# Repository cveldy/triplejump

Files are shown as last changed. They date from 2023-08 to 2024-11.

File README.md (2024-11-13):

# triplejump

Leverless (Hitbox-style) fighting game controller with ~~three~~ two jump options.

`TODO: One or more images`

## About

This controller is distinguished by its split-hand configuration and angled keyclusters, mitigating the RSI-potential of the standard "hands-together-but-parallel" layout popularized by the Hitbox. The goal is to keep the entire device relatively small while still providing a meaningful ergonomic benefit.

Another notable aspect of the layout is the 10 button right hand cluster. The closeness of the keys in this keyboard-like format makes multi-key inputs (e.g., `LP+LK`) harder than usual to press. Promoting `R3` and `L3` into "first class" buttons mitigates this drawback by providing more locations for macros (the legal kind you can map in-game).

Lastly are the titular ~~three~~ two up buttons. This allows the same handed-preference for jumping (and ability to double-tap using both thumbs) from the normal layout.

Powering this device is OpenStick's excellent [GP2040-CE](https://github.com/OpenStickCommunity/GP2040-CE) gamepad firmware. Please see that repository for information about configuration, console compatibility, and all the rest.

## Creation

If you want to produce one, you will need some parts.

### PCB

- 1x triplejump PCB, created using the [gerbers.zip](./prod/gerbers.zip) files with an online PCB prototyping service. (e.g., [JLCPCB](https://jlcpcb.com/).)
- 1x [RP2040-Zero](https://www.waveshare.com/rp2040-zero.htm).
- 5x 6x6mm Panel PCB Momentary Tactile Mini Push Button Switch DIP 4pin.
- 15x Kailh Choc v1 Hotswap Sockets (PG1350).

### Keys

- 15x Kailh Choc v1 Switches (recommended: linear switches with low actuation force).
- 13x Kailh Choc-compatible 1u Keycaps.
- 2x Kailh Choc-compatible 1.5u Keycaps.

### Case

This case was designed with MBK profile Choc keycaps in mind and may or may not be compatible with other keycaps.

- Laser Cut Acrylic Layers: [Bottom](<./prod/case_layer0_1.5mm.dxf>), [Lower-Middle](<./prod/case_layer1_3mm.dxf>), [Upper-Middle](<./prod/case_layer2_4.5mm.dxf), [Top](<./prod/case_layer3_1.5mm.dxf>)
  - The filenames include how thick each layer should be.
  - The PCB goes between the two middle layers.
- 6x M3 x 12mm Bolts.
- 6x M3 x 6mm Barrel Nuts.
- OPTIONAL: Non-slip Feet or Pads.

### Assembly

- Soldering Equipment.
- Screwdriver.

### Firmware

- The [Latest GP2040-CE Release](https://github.com/OpenStickCommunity/GP2040-CE/releases), flashed accoridng to the documentation.
- Pin (Button) Mapping using GP2040-CE's [Web Configurator](https://gp2040-ce.info/#/web-configurator)
  - There is a catch: the firmware assumes a default pin mapping that the triplejump does not use. Until you've remapped the pins, you must hold down L1 instead of S2 (Start) when plugging in the controller to enter the configurator.
  - You could also short pin 1 to ground manually if you haven't installed the switches yet when setting up the firmware.
  - The correct mapping for the triplejump is shown below.

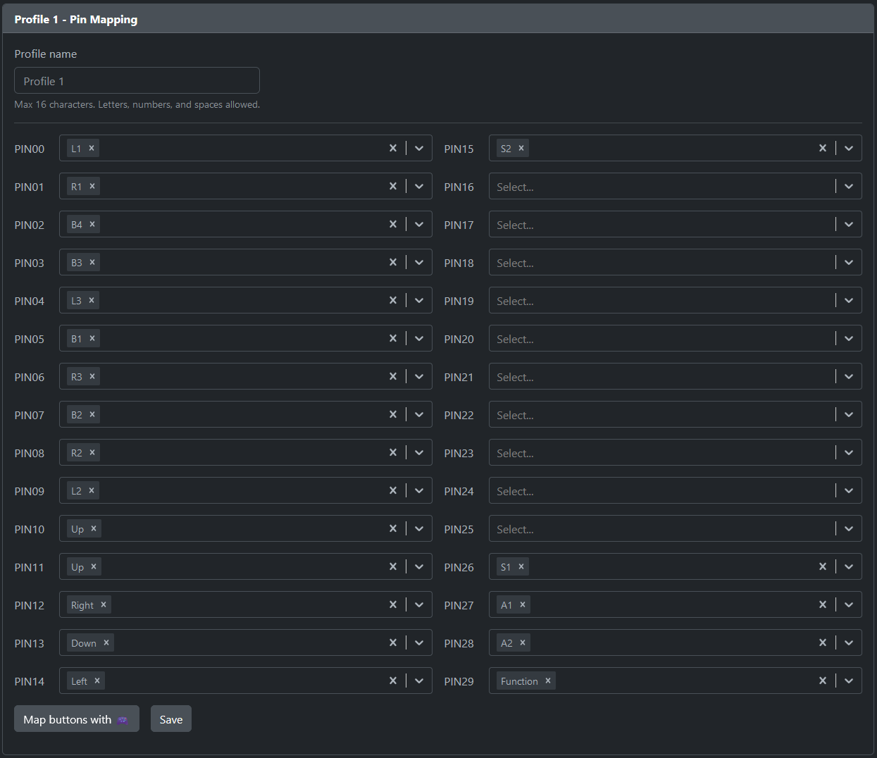
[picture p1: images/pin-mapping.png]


### Art

Optionally, you could print some art and put it between the top two acrylic layers. An [Art Template](<./prod/triplejump_art_template.psd>) is provided, though I haven't tested it personally.

## Acknowledgments

- [GrooveBob](https://github.com/GroooveBob)'s [Stress](https://github.com/GroooveBob/Stress), which helped inspire this design.
- [jfedor2](https://github.com/jfedor2)'s [Flatbox](https://github.com/jfedor2/flatbox), which helped inspire this design.
- [Afternoon Labs](https://github.com/afternoonlabs)' [Breeze](https://github.com/afternoonlabs/BreezeKeyboard), which helped inspire this design and layout.
- [ruiqimao](https://github.com/ruiqimao)'s [Keyboard PCB Guide](https://github.com/ruiqimao/keyboard-pcb-guide), which led me through the entire PCB creation process.
- [crides](https://github.com/crides)'s [Kleeb](https://github.com/crides/kleeb) Kicad library, whose symbols and footprints are present in the PCB schematic and design.
- [daprice](https://github.com/daprice)'s [keyswitches.pretty](https://github.com/daprice/keyswitches.pretty) Kicad library, whose footprints are present in the PCB design. [CC BY 4.0](https://creativecommons.org/licenses/by/4.0/)
- [Sadek Baroudi](https://github.com/sadekbaroudi)'s [Keyboard Case Design](https://kbd.news/Keyboard-Case-Design-1764.html) article, which showed the process for exporting the PCB into a form usable during case design.
- [OpenStickCommunity](https://github.com/OpenStickCommunity)'s [GP2040-CE](https://github.com/OpenStickCommunity/GP2040-CE), whose firmware makes the silicon useful and whose Discord community was extremely helpful.

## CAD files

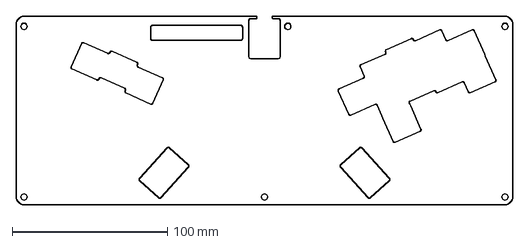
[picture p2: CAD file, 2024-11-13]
prod/case_layer2_4.5mm.dxf
320.0 x 121.5 mm

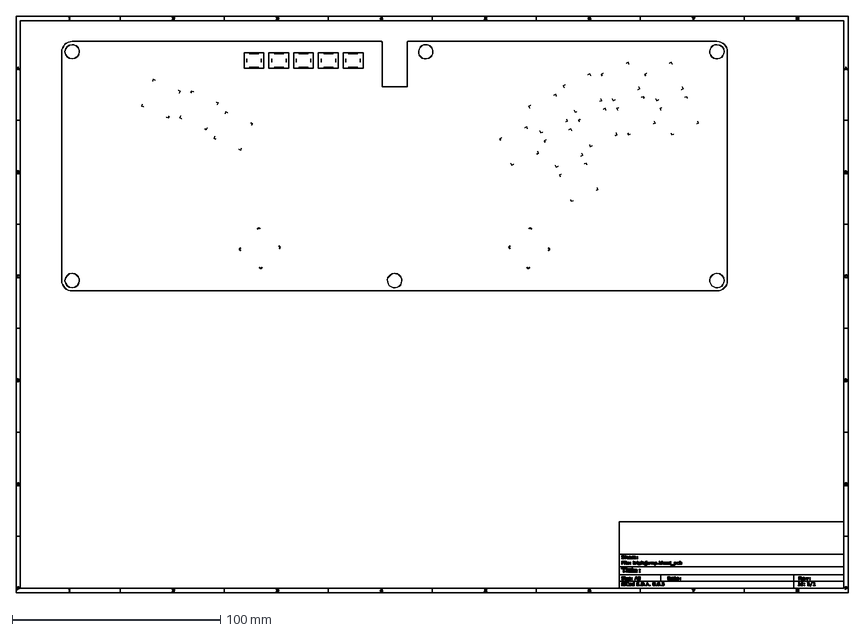
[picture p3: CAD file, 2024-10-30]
src/triplejump-brd.dxf
400.0 x 277.0 mm

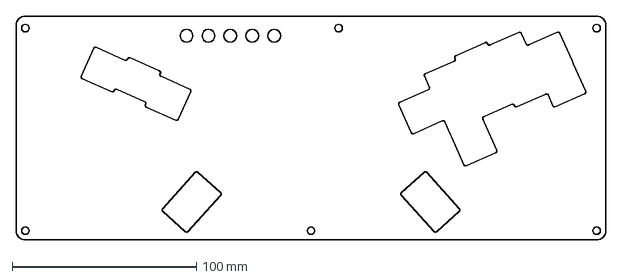
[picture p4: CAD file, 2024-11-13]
prod/case_layer3_1.5mm.dxf
320.0 x 121.5 mm

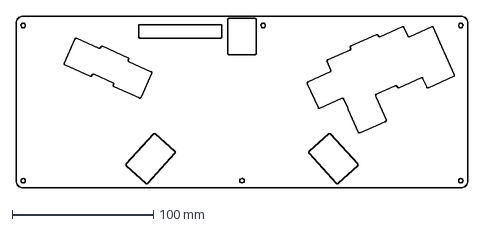
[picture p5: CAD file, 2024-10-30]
prod/case_layer1_3mm.dxf
320.0 x 121.5 mm

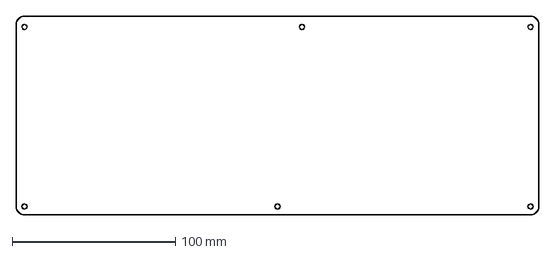
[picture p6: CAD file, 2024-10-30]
prod/case_layer0_1.5mm.dxf
320.0 x 121.5 mm

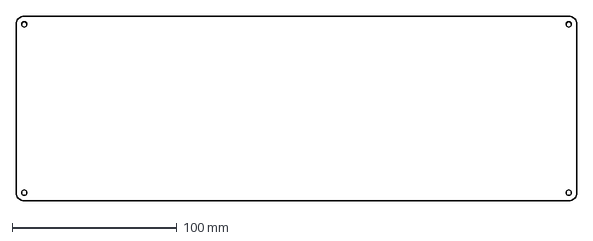
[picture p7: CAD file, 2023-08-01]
prod/case_layer0_1-2mm.dxf
340.0 x 112.0 mm

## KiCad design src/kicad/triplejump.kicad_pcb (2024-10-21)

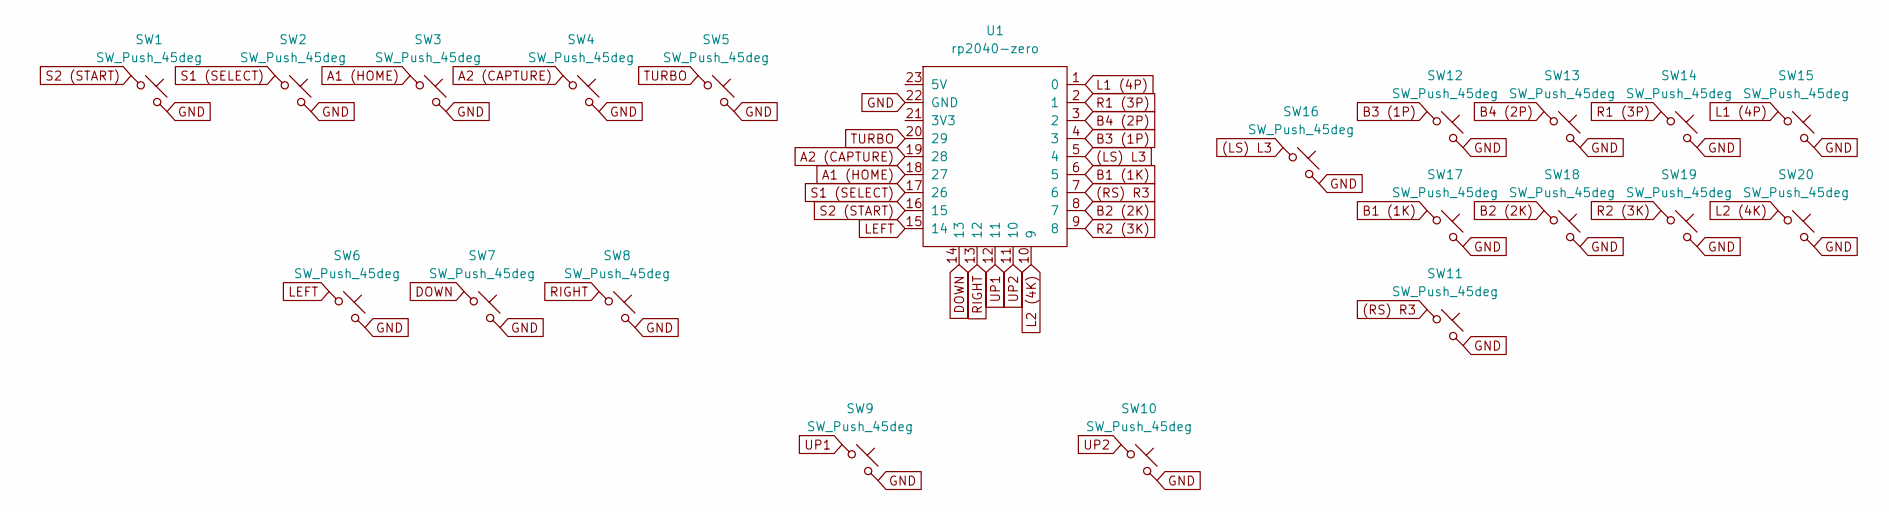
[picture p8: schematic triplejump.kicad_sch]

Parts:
SW1, SW2, SW3, SW4: SW_Push_45deg; SW_PUSH_6mm
SW5, SW6, SW7, SW8, SW9, SW10, SW11, SW12, SW13, SW14, SW15, SW16, SW17, SW18, SW19, SW20: SW_Push_45deg; Kailh_socket_PG1350
U1: rp2040-zero; rp2040-zero-tht

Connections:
(LS) L3: SW16.1, U1.5 (4)
(RS) R3: SW11.1, U1.7 (6)
A1 (HOME): SW3.1, U1.18 (27)
A2 (CAPTURE): SW4.1, U1.19 (28)
B1 (1K): SW17.1, U1.6 (5)
B2 (2K): SW18.1, U1.8 (7)
B3 (1P): SW12.1, U1.4 (3)
B4 (2P): SW13.1, U1.3 (2)
DOWN: SW7.1, U1.14 (13)
GND: SW1.2, SW2.2, SW3.2, SW4.2, SW5.2, SW6.2, SW7.2, SW8.2, SW9.2, SW10.2, SW11.2, SW12.2, SW13.2, SW14.2, SW15.2, SW16.2, SW17.2, SW18.2, SW19.2, SW20.2, U1.22 (GND)
L1 (4P): SW15.1, U1.1 (0)
L2 (4K): SW20.1, U1.10 (9)
LEFT: SW6.1, U1.15 (14)
R1 (3P): SW14.1, U1.2 (1)
R2 (3K): SW19.1, U1.9 (8)
RIGHT: SW8.1, U1.13 (12)
S1 (SELECT): SW2.1, U1.17 (26)
S2 (START): SW1.1, U1.16 (15)
TURBO: SW5.1, U1.20 (29)
UP1: SW9.1, U1.12 (11)
UP2: SW10.1, U1.11 (10)

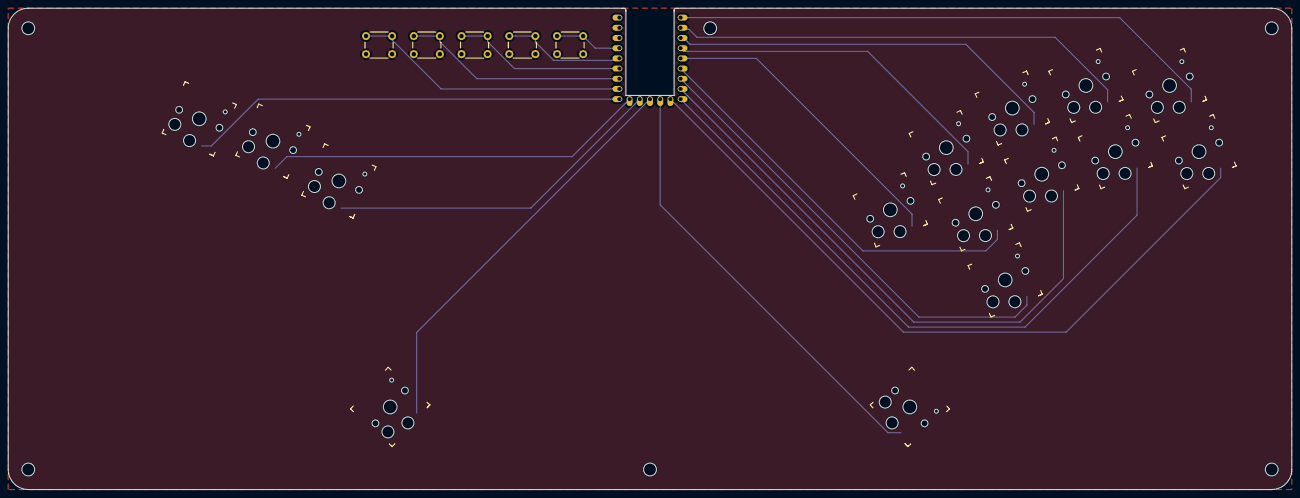
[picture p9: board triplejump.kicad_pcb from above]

Board: 2 copper layers, 320.0 x 120.0 mm, 27 parts (0 on the bottom side), 21 nets.

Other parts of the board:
M3, M3#2, M3#3, M3#4, M3#5, M3#6: MountingHole_3.2mm_M3

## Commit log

2023-07-01 Catching repo up to current state: kicad done (hopefully)
    [triplejump-B_Cu.gbl, triplejump-B_Mask.gbs, triplejump-B_Paste.gbp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]
2023-07-04 Updated PCB (and gerbers) to fix subtle UP 1 missalignment; remove one NPTH
    [triplejump-B_Cu.gbl, triplejump-B_Mask.gbs, triplejump-B_Paste.gbp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]
2023-07-04 Creating directories for case creation, starting with DXF->SVG exports of PCB
    [triplejump-brd.dxf]
2023-07-04 First drafts of case design (adding archives to repo, can't seem to move fusion360 working docs w/ free version)
    [case v2.f3d, case-bottom v20.f3d, case-top v2.f3d]
2023-07-04 Added stl files for first draft of case, both the raw F360 output and the version auto-fixed with other software
    [case-bottom (repaired).stl, case-bottom.stl, case-top (repaired).stl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]
2023-07-04 Attempting to update case links in README.
2023-07-11 Removed central m3 screwhole from pcb.
    [triplejump-B_Cu.gbl, triplejump-B_Mask.gbs, triplejump-B_Paste.gbp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]
2023-07-19 Redesigned case after failure of first prototype. Now more high profile, has a better USB-C cutout, and is overall much less material.
    [case v2.f3d, case-bottom (repaired).stl, case-bottom v20.f3d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]
2023-07-19 Fixed significant issue with v2 of the case.
    [case-bottom (repaired).stl, case-bottom.f3d, case-bottom.stl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]
2023-08-01 Fixed incorrect silkscreen label locations for RT, LB.
    [triplejump-B_Cu.gbl, triplejump-B_Mask.gbs, triplejump-B_Paste.gbp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]
2023-08-01 After 2 failed attempts at 3D printing a case, trying out acrylic instead.
    [case_layer0_1-2mm.dxf, case_layer1_2-3mm.dxf, case_layer2_4-6mm.dxf]
2023-09-08 Finalized case and case assembly information.
    [case-bottom (repaired).stl, case-bottom.stl, case-top-hipro (repaired).stl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]
2024-10-10 Updated PCB for version 2
    [triplejump-B_Cu.gbl, triplejump-B_Mask.gbs, triplejump-B_Paste.gbp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]
2024-10-21 Fixed spacing error in right hand cluster
    [triplejump-B_Cu.gbl, triplejump-B_Mask.gbs, triplejump-B_Paste.gbp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]
2024-10-30 Created new case files for v2
    [case_layer0_1.5mm.dxf, case_layer1_2-3mm.dxf, case_layer1_3mm.dxf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]
2024-10-30 Updated README and pin mapping image.
2024-11-13 Fixed upper case layers and created art template
    [case_layer2_4.5mm.dxf, case_layer3_1.5mm.dxf]
2024-11-13 Updated README to mention art template and switch from threaded inserts to barrel nuts.
